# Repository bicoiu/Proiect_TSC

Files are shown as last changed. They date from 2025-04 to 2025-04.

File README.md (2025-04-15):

# TSC-Project

## BOM (Bill Of Materials)

| Component | Supplier Link | Datasheet |
|---|---|---|
| 112A-TAAR-R03 | [Model](https://store.comet.srl.ro/Catalogue/Product/43497/) | [Datasheet](https://www.snapeda.com/parts/112A-TAAR-R03/Attend/datasheet/) |
| 744043680 | [Model](https://ro.mouser.com/ProductDetail/Wurth-Elektronik/744043680?qs=PGXP4M47uW6VkZq%252BkzjrHA%3D%3D)| [Datasheet](https://www.we-online.com/components/products/datasheet/744043680.pdf) |
| BD5229G-TR | [Model](https://componentsearchengine.com/part-view/BD5229G-TR/ROHM%20Semiconductor) | [Datasheet](https://fscdn.rohm.com/en/products/databook/datasheet/ic/power/voltage_detector/bd52xxg-e.pdf) |
| Capacitor 0402 | [Model](https://ro.mouser.com/c/passive-components/capacitors/ceramic-capacitors/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) | [Datasheet](https://componentsearchengine.com/Datasheets/2/CC0402MRX5R5BB106.pdf) |
| CPH3225A | [Model](https://www.snapeda.com/parts/CPH3225A/Seiko+Instruments/view-part/?ref=snap) | [Datasheet](https://www.snapeda.com/parts/CPH3225A/Seiko%20Instruments/datasheet/) |
| Custom Button | [Model](https://industry.panasonic.com/global/en/products/control/switch/light-touch/number/evqpuj02k) | [Datasheet](https://industry.panasonic.com/global/en/downloads?tab=catalog&small_g_cd=203&part_no=EVQPUJ02K) |
| DS3231SN | [Model](https://www.snapeda.com/parts/DS3231SN%23/Analog+Devices/view-part/?ref=eda) | [Datasheet](https://www.snapeda.com/parts/DS3231SN%23/Analog%20Devices/datasheet/) |
| ESP32 WROVER 0805 Capacitor | [Model](https://componentsearchengine.com/part-view/ESP32-WROVER-IB/Espressif%20Systems) | [Datasheet](https://4donline.ihs.com/images/VipMasterIC/IC/ESPS/ESPS-S-A0016256762/ESPS-S-A0016256762-1.pdf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) |
| ESP32 WROVER BME680 Sensor | [Model](https://www.snapeda.com/parts/BME680/Bosch/view-part/?welcome=home) | [Datasheet](https://www.bosch-sensortec.com/media/boschsensortec/downloads/datasheets/bst-bme680-ds001.pdf) |
| ESP32 WROVER MCP73831 Power Management | [Model](https://www.snapeda.com/parts/BME680/Bosch/view-part/?welcome=home) | [Datasheet](https://www.snapeda.com/parts/MCP73831T-2ACI/OT/Microchip/datasheet/) |
| ESP32C6 Varistor 1812 | [Model](https://componentsearchengine.com/part-view/ESP32-C6-MINI-1-H4/Espressif%20Systems) | [Datasheet](https://4donline.ihs.com/images/VipMasterIC/IC/ESPS/ESPS-S-A0018537656/ESPS-S-A0018537656-1.pdf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) |
| ESP32C6 WROOM-1-N8 | [Model](https://www.snapeda.com/parts/ESP32-C6-WROOM-1-N8/Espressif+Systems/view-part/?ref=eda) | [Datasheet](https://www.snapeda.com/parts/ESP32-C6-WROOM-1-N8/Espressif%20Systems/datasheet/) |
| FH34SRJ-24S-0.5SH | [Model](https://ro.mouser.com/ProductDetail/Hirose-Connector/FH34SRJ-24S-0.5SH99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) | [Datasheet](https://www.snapeda.com/parts/FH34SRJ-24S-0.5SH(99)/Hirose%20Connector/datasheet/) |
| LED Chip 0603 | [Model](https://www.snapeda.com/parts/KP-1608SURCK/Kingbright/view-part/?ref=search&t=LED%200603) | [Datasheet](https://www.snapeda.com/parts/KP-1608SURCK/Kingbright/datasheet/) |
| MAX17048G+T10 | [Model](https://www.snapeda.com/parts/MAX17048G+T10/Analog+Devices/view-part/?ref=eda) | [Datasheet](https://www.snapeda.com/parts/MAX17048G+T10/Analog%20Devices/datasheet/) |
| MBR0530 Schottky Diode| [Model](https://www.snapeda.com/parts/MBR0530/Onsemi/view-part/?ref=snap) | [Datasheet](https://www.snapeda.com/parts/MBR0530/ON%20Semiconductor/datasheet/) |
| PGB1010603MR | [Model](https://www.snapeda.com/parts/PGB1010603MR/Littelfuse/view-part/?ref=eda) | [Datasheet](https://www.snapeda.com/parts/PGB1010603MR/Littelfuse%20Inc./datasheet/) |
| QWIIC Connector | [Model](https://www.snapeda.com/parts/PRT-14417/SparkFun/view-part/) | [Datasheet](https://www.snapeda.com/parts/PRT-14417/SparkFun%20Electronics/datasheet/) |
| RCL CPOL 3528 | [Model](https://www.snapeda.com/parts/CPH3225A/Seiko+Instruments/view-part/?ref=eda) | [Datasheet](https://s3.amazonaws.com/snapeda/datasheet/TAJB475K025RNJ_AVX.pdf) |
| Resistor 0402 | [Model](https://grabcad.com/library/resistor-0402-1) | [Datasheet](https://www.yageo.com/upload/media/product/products/datasheet/rchip/PYu-RC_Group_51_RoHS_L_12.pdf) |
| SI1308EDL-T1-GE3 MOSFET | [Model](https://www.snapeda.com/parts/SI1308EDL-T1-GE3/Vishay+Siliconix/view-part/?welcome=home&ref=eda) | [Datasheet](https://www.snapeda.com/parts/SI1308EDL-T1-GE3/Vishay%20Siliconix/datasheet/) |
| SJ | [Model](https://grabcad.com/library/solder-jumpers-1) | [Datasheet]() |
| USB4110-GF-A | [Model](https://componentsearchengine.com/part-view/USB4110-GF-A/GCT%20(GLOBAL%20CONNECTOR%20TECHNOLOGY))| [Datasheet](https://gct.co/files/drawings/usb4110.pdf) |
| USBLC6-2SC6Y | [Model](https://www.snapeda.com/parts/USBLC6-2SC6Y/STMicroelectronics/view-part/?welcome=home&ref=eda)  | [Datasheet](https://www.snapeda.com/parts/USBLC6-2SC6Y/STMicroelectronics/datasheet/) |
| W25Q512JVEIQ | [Model](https://www.snapeda.com/parts/W25Q512JVEIQ/Winbond+Electronics/view-part/?ref=eda) | [Datasheet](https://www.winbond.com/resource-files/W25Q512JV%20SPI%20RevB%2006252019%20KMS.pdf) |
| XC6220A331MR-G | [Model](https://componentsearchengine.com/part-view/XC6220A331MR-G/Torex) | [Datasheet](https://product.torexsemi.com/system/files/series/xc6220.pdf) |

## Hardware Description

1. **Microcontroller - ESP32-C6-WROOM-1-N8**  
   - Architecture: RISC-V 32-bit  
   - Clock Speed: 160 MHz  
   - Wireless Connectivity: 2.4 GHz Wi-Fi 6, Bluetooth 5.0  

2. **Power Management & Battery**  
   - Battery Type: Li-Po (Lithium Polymer), 3.7V, 1800mAh  
   - Charging Circuit: MCP73831T  
   - Input Voltage: 5V via USB-C  
   - Protection Features: Overcharge and deep discharge protection  
   - Voltage Regulator: LDO regulator for stable 3.3V supply  

3. **Display - E-Paper (E-Ink)**  
   - Size: 7.5 inches  
   - Resolution: 800x480 pixels  
   - Interface: SPI  

4. **SD Card Module**  
   - Type: MicroSD (FAT32 supported)  
   - Interface: SPI  

5. **External NOR Flash**  
   - Capacity: 64MB  
   - Interface: SPI  

6. **Environmental Sensor - BME688**  
   - Senses temperature, humidity, pressure, and gas  
   - Interface: I2C  

7. **Real-Time Clock (RTC) - DS3231SN**  
   - Maintains accurate time/date  
   - Interface: I2C  

8. **USB-C Connector & ESD Protection**  
   - Power input and data transfer  
   - ESD protection and Schottky diode for reverse polarity  

9. **Buttons & User Input**  
   - Tactile push buttons  

10. **Communication Interfaces**  
   - GPIO, SPI, I2C, UART, Wi-Fi, Bluetooth  

## Power Consumption Estimation

| Component | Current Draw (mA) | Voltage (V) | Power (mW) |
|---|---|---|---|
| ESP32-C6 (Wi-Fi active)  | 200 | 3.3 | 660 |
| E-Paper Display (Updating) | 40 | 3.3 | 132 |
| BME688 Sensor (Measuring)  | 3.1 | 3.3 | 10.23 |
| RTC Module (Active) | 0.15 | 3.3 | 0.495 |
| SD Card (Active) | 50 | 3.3 | 165 |
| External NOR Flash | 25 | 3.3 | 82.5 |
| **Total** | ~318.5mA | 3.3 | ~1050.72 |

## ESP32-C6 Pin Mapping

| Component | ESP32-C6 Pins | Interface | Purpose |
|---|---|---|---|
| **E-Paper Display** | IO7 (MOSI), IO6 (SCK), IO10 (CS), IO5 (DC), IO23 (RST), IO3 (BUSY) | SPI  | Transfers image data and controls e-paper state |
| **MicroSD Card** | IO7 (MOSI), IO6 (SCK), IO4 (SS_SD), IO2 (MISO) | SPI  | Storage and retrieval of e-books |
| **Environmental Sensor (BME688)** | IO21 (SDA), IO22 (SCL) | I2C | Reads temperature, humidity, pressure, and gas levels |
| **RTC Module (DS3231)** | IO21 (SDA), IO22 (SCL), IO18 (RST), IO1 (32KHz), IO0 (INT_RTC) | I2C | Maintains time tracking when system is off |
| **External NOR Flash** | IO11 (CS), IO6 (SCK), IO2 (MISO), IO7 (MOSI) | SPI  | Additional storage for data |
| **Battery Monitoring** | IO21 (SDA), IO22 (SCL) | I2C | Reads battery voltage and charge status |
| **USB-C Connection** | GPIOs via voltage regulation | USB | Powers and programs the ESP32-C6 |
| **Control Buttons** | IO9 (BOOT), IO15 (CHANGE), EN (RESET)  | GPIO | User input for device interactions |

## Additional Design Notes

### Footprint Adjustments
- **Diode (SMD-Hole)**: The original footprint had pad holes too small for reliable soldering. Pads were updated to 35mil x 190mil.  
- **U4 – MAX17048G+T10**: VBAT power trace width was 0.3mm, while pin widths were only 0.27mm. Adjusted pin size to match trace width.

### Routing & Ground Plane
- Power traces are on the top layer; ~150 vias used for bottom-layer signals.  
- Ground plane on both top and bottom layers for low-impedance grounding and reduced EMI.

### Component Placement
- External ports align with the OpenBook enclosure for accessibility.  
- Test pads near board edges for easy debugging.  
- 100nF decoupling capacitors placed close to IC power pins for noise reduction.

### Schematic & 3D Model Issues
- A net named GND1 appeared but was not functional; removed after review.  
- 3D model updates caused pin order reversals for certain 2-pin components, fixed by rotating 180 degrees.

### Enclosure & 3D Integration
- An alternative enclosure was tested with a custom color.  
- 3D components were imported via two methods depending on their usage frequency.

### Difficulties Encountered
- Am intampinat dificultati la realizarea schematicului pana am inceput sa ma documentez.  
- In etapa de proiectare PCB, cea mai mare provocare a fost sa asez toate componentele in dimensiunile cerute.  
- Rutarea finala a fost de asemenea dificila, necesitand mai multe iteratii pentru a organiza corespunzator toate traseele.

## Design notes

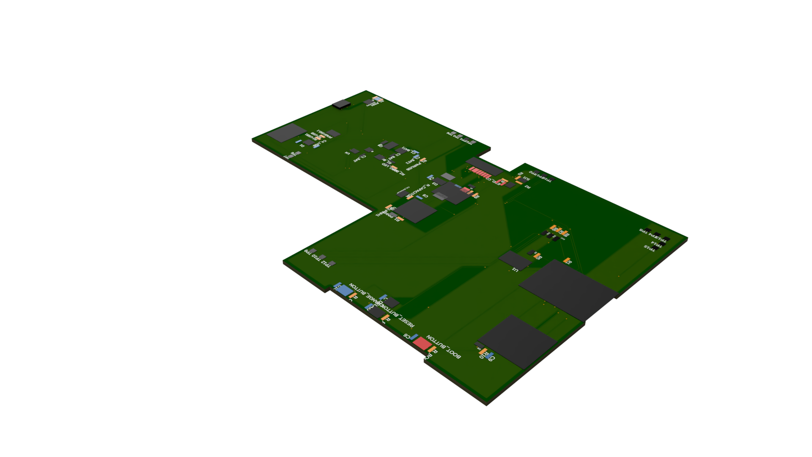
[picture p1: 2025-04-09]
Hardware/board.png

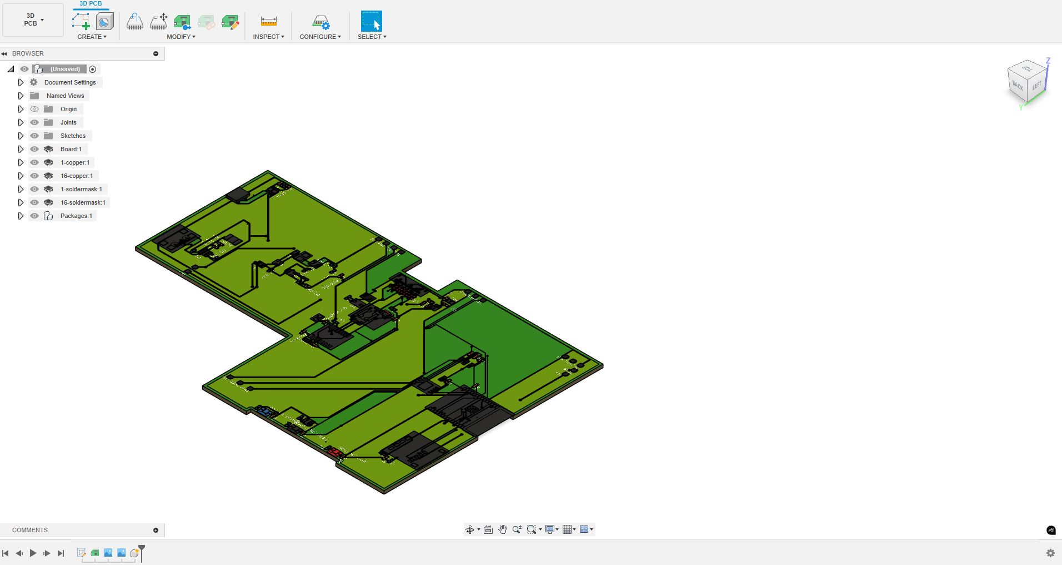
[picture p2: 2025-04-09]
Images/bord.png

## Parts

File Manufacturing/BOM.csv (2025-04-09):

Qty | Value | Device | Footprint Name | Parts | Detailed Description | ARROW_PART_NUMBER | ARROW_PRICE-STOCK | AVAILABILITY | CENTROID_NOT_SPECIFIED | CHECK_PRICES | COPYRIGHT | DATASHEET | DESCRIPTION | DIGIKEY_DESCRIPTION | DIGIKEY_PART_NUMBER | HEIGHT | LEAD_FREE | MANUFACTURER_NAME | MANUFACTURER_PART_NUMBER | MF | MFR_NAME | MOUSER_PART_NUMBER | MOUSER_PRICE-STOCK | MOUSER_TESTING_PART_NUMBER | MOUSER_TESTING_PRICE-STOCK | MP | MPN | PACKAGE | POPULARITY | PREFIX | PRICE | PROD_ID | PURCHASE-URL | ROHS | SNAPEDA_LINK | SPICEMODEL | SPICEPREFIX | TEMPERATURE_RANGE_HIGH | TEMPERATURE_RANGE_LOW | TP_SIGNAL_NAME | VALUE
1 |  | ADAFRUIT_LEDCHIP-LED0603 | ADAFRUIT_CHIP-LED0603 | CHG_LED | LED
1 |  | SJ | SJ | SJ1 | SMD solder JUMPER |  |  |  |  |  |  |  |  |  |  |  |  |  |  |  |  |  |  |  |  |  |  |  | 3
1 | 0.1uF/50V | ESP32_WROVER_EAGLE-LTSPICE_CC0402 | ESP32_WROVER_EAGLE-LTSPICE_C0402 | C18 | CAPACITOR, European symbol |  |  |  |  |  |  |  |  |  |  |  |  |  |  |  |  |  |  |  |  |  |  |  |  |  |  |  |  |  |  | NONE | C
1 | 0.47 | ESP32_WROVER_EAGLE-LTSPICE_RR0402 | ESP32_WROVER_EAGLE-LTSPICE_R0402 | R6 | RESISTOR, European symbol |  |  |  |  |  |  |  |  |  |  |  |  |  |  |  |  |  |  |  |  |  |  |  |  |  |  |  |  |  |  | NONE | R
1 | 100K | ESP32_WROVER_EAGLE-LTSPICE_RR0402 | ESP32_WROVER_EAGLE-LTSPICE_R0402 | R1_PWRUSB | RESISTOR, European symbol |  |  |  |  |  |  |  |  |  |  |  |  |  |  |  |  |  |  |  |  |  |  |  |  |  |  |  |  |  |  | NONE | R
9 | 100nF | ESP32_WROVER_EAGLE-LTSPICE_CC0402 | ESP32_WROVER_EAGLE-LTSPICE_C0402 | C1, C6, C8, C21, C22, C23, C25, C26, C_DELAY | CAPACITOR, European symbol |  |  |  |  |  |  |  |  |  |  |  |  |  |  |  |  |  |  |  |  |  |  |  |  |  |  |  |  |  |  | NONE | C
1 | 100uF | RCL_CPOL-EUCT3528 | RCL_CT3528 | TANT | POLARIZED CAPACITOR, European symbol |  |  |  |  |  |  |  |  |  |  |  |  |  |  |  |  |  |  |  |  |  |  |  | 0 |  |  |  |  |  |  |  | C
15 | 10K | ESP32_WROVER_EAGLE-LTSPICE_RR0402 | ESP32_WROVER_EAGLE-LTSPICE_R0402 | R1_PINH, R1_PINH1, R2-PINH, R2-PINH1, R7, R17, R18, R19, R20, R21, R22, R_BOOT, R_CHANGE, R_CL1, R_RESET | RESISTOR, European symbol |  |  |  |  |  |  |  |  |  |  |  |  |  |  |  |  |  |  |  |  |  |  |  |  |  |  |  |  |  |  | NONE | R
1 | 10uF | ESP32_WROVER_EAGLE-LTSPICE_CC0402 | ESP32_WROVER_EAGLE-LTSPICE_C0402 | C7 | CAPACITOR, European symbol |  |  |  |  |  |  |  |  |  |  |  |  |  |  |  |  |  |  |  |  |  |  |  |  |  |  |  |  |  |  | NONE | C
1 | 112A-TAAR-R03_ATTEND | 112A-TAAR-R03_ATTEND | 112ATAARR03ATTEND | J2 | Micro SD Card Socket, Push-Push Type, Top Mount, SMT, H=1.83mm, 10u |  |  |  |  |  |  |  | Micro SD Card Socket, Push-Push Type, Top Mount, SMT, H=1.83mm, 10u |  |  | 1.9mm |  | ATTEND | 112A-TAAR-R03 ATTEND
1 | 15 | ESP32_WROVER_EAGLE-LTSPICE_RR0402 | ESP32_WROVER_EAGLE-LTSPICE_R0402 | R_CAPACITOR | RESISTOR, European symbol |  |  |  |  |  |  |  |  |  |  |  |  |  |  |  |  |  |  |  |  |  |  |  |  |  |  |  |  |  |  | NONE | R
1 | 1uF | ESP32_WROVER_EAGLE-LTSPICE_CC0402 | ESP32_WROVER_EAGLE-LTSPICE_C0402 | C24 | CAPACITOR, European symbol |  |  |  |  |  |  |  |  |  |  |  |  |  |  |  |  |  |  |  |  |  |  |  |  |  |  |  |  |  |  | NONE | C
9 | 1uF/50V | ESP32_WROVER_EAGLE-LTSPICE_CC0402 | ESP32_WROVER_EAGLE-LTSPICE_C0402 | C11, C12, C13, C14, C15, C16, C17, C19, C20 | CAPACITOR, European symbol |  |  |  |  |  |  |  |  |  |  |  |  |  |  |  |  |  |  |  |  |  |  |  |  |  |  |  |  |  |  | NONE | C
1 | 2.2 | ESP32_WROVER_EAGLE-LTSPICE_RR0402 | ESP32_WROVER_EAGLE-LTSPICE_R0402 | R5 | RESISTOR, European symbol |  |  |  |  |  |  |  |  |  |  |  |  |  |  |  |  |  |  |  |  |  |  |  |  |  |  |  |  |  |  | NONE | R
1 | 200 | ESP32_WROVER_EAGLE-LTSPICE_RR0402 | ESP32_WROVER_EAGLE-LTSPICE_R0402 | R1_BAT | RESISTOR, European symbol |  |  |  |  |  |  |  |  |  |  |  |  |  |  |  |  |  |  |  |  |  |  |  |  |  |  |  |  |  |  | NONE | R
2 | 20V/4.2A/52mO/1.4W | ESP32_WROVER_SPARKFUN-DISCRETESEMI_MOSFET_PCH-DMG2305UX-7 | ESP32_WROVER_SPARKFUN-DISCRETESEMI_SOT23-3 | Q1, Q3 | P-channel MOSFETs |  |  |  |  |  |  |  |  |  |  |  |  |  |  |  |  |  |  |  |  |  |  |  |  |  |  | TRAN-14388 |  |  |  |  |  |  |  |  | 20V/4.2A/52mO/1.4W
2 | 2K | ESP32_WROVER_EAGLE-LTSPICE_RR0402 | ESP32_WROVER_EAGLE-LTSPICE_R0402 | R2_BAT, R10 | RESISTOR, European symbol |  |  |  |  |  |  |  |  |  |  |  |  |  |  |  |  |  |  |  |  |  |  |  |  |  |  |  |  |  |  | NONE | R
5 | 4.7uF | ESP32_WROVER_EAGLE-LTSPICE_CC0402 | ESP32_WROVER_EAGLE-LTSPICE_C0402 | C1_BAT, C1_BAT1, C1_BAT2, C2, C2_BAT | CAPACITOR, European symbol |  |  |  |  |  |  |  |  |  |  |  |  |  |  |  |  |  |  |  |  |  |  |  |  |  |  |  |  |  |  | NONE | C
2 | 5k1 | ESP32_WROVER_EAGLE-LTSPICE_RR0402 | ESP32_WROVER_EAGLE-LTSPICE_R0402 | R2-USB1, R2-USB2 | RESISTOR, European symbol |  |  |  |  |  |  |  |  |  |  |  |  |  |  |  |  |  |  |  |  |  |  |  |  |  |  |  |  |  |  | NONE | R
1 | 68uH | 744043680IND_4828-WE-TPC_WRE | IND_4828-WE-TPC_WRE | L2 |  |  |  |  |  |  | Copyright (C) 2024 Ultra Librarian. All rights reserved. |  |  |  |  |  |  |  | 744043680 |  | Wurth Electronics
1 | BD5229G-TR | BD5229G-TR | SOT95P280X125-5N | IC2 | Voltage Detector with Adjustable Delay Time: CMOS processes are utilized to develop high precision, low current consumption CMOS reset ICs that allow arbitrary setting of the delay time. The extensive lineup includes both Nch Open Drain and CMOS output types in a wide range of detection voltages (from 2.3V to 6.0V, in 0.1V steps), enabling selection of the ideal solution based on customer requirements. In addition, the entire series is of course both lead-free and RoHS-compliant. |  |  |  |  |  |  |  | Voltage Detector with Adjustable Delay Time: CMOS processes are utilized to develop high precision, low current consumption CMOS reset ICs that allow arbitrary setting of the delay time. The extensive lineup includes both Nch Open Drain and CMOS output types in a wide range of detection voltages (from 2.3V to 6.0V, in 0.1V steps), enabling selection of the ideal solution based on customer requirements. In addition, the entire series is of course both lead-free and RoHS-compliant. |  |  | 1.25mm |  | ROHM Semiconductor | BD5229G-TR |  |  | 755-BD5229G-TR | https://www.mouser.co.uk/ProductDetail/ROHM-Semiconductor/BD5229G-TR?qs=4kLU8WoGk0vvnhrrYwdszw%3D%3D
1 | BME688 | ESP32_WROVER_BME680_BME680 | ESP32_WROVER_BME680_PSON80P300X300X100-8N | U3 | Integrated Environmental Unit |  |  | Unavailable |  |  |  |  | Integrated Environmental Unit |  |  |  |  |  |  | Bosch Sensortec |  |  |  |  |  | BME680 |  | LGA-8 Bosch Tools |  |  | None
1 | BOOT_BUTTON | BUTTON_CUSYOMV1 | MYBUTTON | U$2
1 | C10_SUPERCAP | ESP32_WROVER_EAGLE-LTSPICE_CC0402 | ESP32_WROVER_EAGLE-LTSPICE_C0402 | CPH3225A | CAPACITOR, European symbol |  |  |  |  |  |  |  |  |  |  |  |  |  |  |  |  |  |  |  |  |  |  |  |  |  |  |  |  |  |  | NONE | C
1 | CHANGE_BUTTON | BUTTON_CUSYOMV1 | MYBUTTON | PUSH
1 | DS3231SN# | DS3231SN# | SOIC127P1032X265-16N | U5 | Real Time Clock Serial 16-Pin SOIC W T/R Check availability |  |  | In Stock |  | https://www.snapeda.com/parts/DS3231SN%23/Analog+Devices/view-part/?ref=eda |  |  | Extremely Accurate I²C-Integrated RTC/TCXO/Crystal |  |  |  |  |  |  | Analog Devices |  |  |  |  |  | DS3231SN# |  | SOIC-16 Maxim |  |  | None |  | https://www.snapeda.com/api/url_track_click_mouser/?unipart_id=99048&manufacturer=Analog Devices&part_name=DS3231SN#&search_term=None |  | https://www.snapeda.com/parts/DS3231SN%23/Analog+Devices/view-part/?ref=snap
1 | ESP32-C6-WROOM-1-N8 | ESP32-C6-WROOM-1-N8 | XCVR_ESP32-C6-WROOM-1-N8 | U2 | Check availability |  |  | In Stock |  | https://www.snapeda.com/parts/ESP32-C6-WROOM-1-N8/Espressif+Systems/view-part/?ref=eda |  |  | Multiprotocol Modules ESP32-C6 module, Wi-Fi 6 in 2.4 GHz band, Bluetooth 5, Zigbee 3.0 and Thread. ESP34-WROOM Compatible - ENGINEERING SAMPLE |  |  |  |  |  |  | Espressif Systems |  |  |  |  |  | ESP32-C6-WROOM-1-N8 |  | None |  |  | None |  |  |  | https://www.snapeda.com/parts/ESP32-C6-WROOM-1-N8/Espressif+Systems/view-part/?ref=snap
1 | ESP32C6_VARISTORCN1812 | ESP32C6_VARISTORCN1812 | ESP32C6_VARISTOR_CT/CN1812 | PFMF.050.1 | VARISTOR |  |  |  |  |  |  |  |  |  |  |  |  |  |  |  |  |  |  |  |  |  |  |  | 0
2 | ESP32_WROVER_AVX---SD0805S020S1R0_AVX_SD0805S020S1R0_0_0AVX_SD0805S020S1R0_0_0 | ESP32_WROVER_AVX---SD0805S020S1R0_AVX_SD0805S020S1R0_0_0AVX_SD0805S020S1R0_0_0 | ESP32_WROVER_AVX---SD0805S020S1R0_AVX_SD0805S020S1R0_0 | D2, D6 | Schottky Barrier Rectifier Diode |  |  |  | No |  |  | http://datasheets.avx.com/schottky.pdf |  | DIODE SCHOTTKY 20V 1A 0805 | 478-7800-1-ND |  | yes |  |  | AVX |  | 581-SD0805S020S1R0 |  |  |  |  |  | 0805 (2012 metric) |  | D |  |  |  | yes |  |  |  | +125°C | -55°C
1 | ESP32_WROVER_SPARKFUN-IC-POWER_MCP73831 | ESP32_WROVER_SPARKFUN-IC-POWER_MCP73831 | ESP32_WROVER_SPARKFUN-IC-POWER_SOT23-5 | U1 | MCP73831T Li-Ion, Li-Pol Controller |  |  |  |  |  |  |  |  |  |  |  |  |  |  |  |  |  |  |  |  |  |  |  |  |  |  | IC-09995
1 | FH34SRJ-24S-0.5SH_99_ | FH34SRJ-24S-0.5SH_99_ | FH34SRJ24S05SH99 | J3 | 24 Position FFC, FPC Connector Contacts, Top and Bottom 0.020 (0.50mm) Surface Mount, Right Angle" |  |  |  |  |  |  |  | 24 Position FFC, FPC Connector Contacts, Top and Bottom 0.020 (0.50mm) Surface Mount, Right Angle" |  |  | 1.1mm |  | Hirose | FH34SRJ-24S-0.5SH(99) |  |  | 798-FH34SRJ24S05SH99 | https://www.mouser.co.uk/ProductDetail/Hirose-Connector/FH34SRJ-24S-0.5SH99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
1 | MAX17048G+T10 | MAX17048G+T10 | SON50P200X200X80-9N | U4 | Check availability |  |  | In Stock |  | https://www.snapeda.com/parts/MAX17048G+T10/Analog+Devices/view-part/?ref=eda |  |  | 3µA 1-Cell/2-Cell Fuel Gauge with ModelGauge |  |  |  |  |  |  | Analog Devices |  |  |  |  |  | MAX17048G+T10 |  | TDFN-8 Maxim |  |  | None |  | https://www.snapeda.com/api/url_track_click_mouser/?unipart_id=329239&manufacturer=Analog Devices&part_name=MAX17048G+T10&search_term=None |  | https://www.snapeda.com/parts/MAX17048G+T10/Analog+Devices/view-part/?ref=snap
3 | MBR0530 | MBR0530 | SOD3716X135N | D3, D4, D5 | ON SEMICONDUCTOR - MBR0530 - DIODE, SCHOTTKY, 0.5A, 30V, SOD-123 |  |  | In Stock |  | https://www.snapeda.com/parts/MBR0530/Onsemi/view-part/?ref=eda |  |  | Diode Schottky 30 V 500mA Surface Mount SOD-123 |  |  |  |  |  |  | ON Semiconductor |  |  |  |  |  | MBR0530 |  | SOD-123-2 ON Semiconductor |  |  | None |  | https://www.snapeda.com/api/url_track_click_mouser/?unipart_id=179458&manufacturer=ON Semiconductor&part_name=MBR0530&search_term=None |  | https://www.snapeda.com/parts/MBR0530/Onsemi/view-part/?ref=snap
6 | PGB1010603MR | PGB1010603MR | DIOC1608X36N | D7, D8, D9, D10, D11, D12 | Check availability |  |  | In Stock |  | https://www.snapeda.com/parts/PGB1010603MR/Littelfuse/view-part/?ref=eda |  |  | 150V (Typ) Clamp - Ipp Tvs Diode Surface Mount 0603 (1608 Metric) |  |  |  |  |  |  | Littelfuse Inc. |  |  |  |  |  | PGB1010603MR |  | 0603 Littelfuse Inc. |  |  | None |  | https://www.snapeda.com/api/url_track_click_mouser/?unipart_id=5659453&manufacturer=Littelfuse Inc.&part_name=PGB1010603MR&search_term=None |  | https://www.snapeda.com/parts/PGB1010603MR/Littelfuse/view-part/?ref=snap
1 | QWIIC_RIGHT_ANGLE | QWIIC_CONNECTORJS-1MM | JST04_1MM_RA | J4 | SparkFun I2C Standard Qwiic Connector |  |  |  |  |  |  |  |  |  |  |  |  |  |  |  |  |  |  |  |  |  |  |  |  |  |  | CONN-13694 |  |  |  |  |  |  |  |  | QWIIC_RIGHT_ANGLE
1 | RESET_BUTTON | BUTTON_CUSYOMV1 | MYBUTTON | RESET_BUTTON
1 | SAMACSYS_PARTS_USB4110-GF-A | SAMACSYS_PARTS_USB4110-GF-A | SAMACSYS_PARTS_USB4110GFA | J1 | CONN USB 2.0 TYPE-C R/A SMT |  |  |  |  |  |  |  | CONN USB 2.0 TYPE-C R/A SMT |  |  | 3.26mm |  | GCT (GLOBAL CONNECTOR TECHNOLOGY) | USB4110-GF-A |  |  | 640-USB4110-GF-A | https://www.mouser.co.uk/ProductDetail/GCT/USB4110-GF-A?qs=KUoIvG%2F9IlYiZvIXQjyJeA%3D%3D
1 | SI1308EDL-T1-GE3 | SI1308EDL-T1-GE3 | SOT65P210X110-3N | Q2 | MOSFET N-Ch 30V 1.5A TrenchFET SC70 Vishay Si1308EDL-T1-GE3 N-channel MOSFET Transistor, 1.5 A, 30 V, 3-Pin SC-70 |  |  | In Stock |  | https://www.snapeda.com/parts/SI1308EDL-T1-GE3/Vishay+Siliconix/view-part/?ref=eda |  |  | Si1308EDL-T1-GE3 N-channel MOSFET Transistor, 1.5 A, 30 V, 3-Pin SC-70 | Siliconix / Vishay SI1308EDL-T1-GE3 |  |  |  |  |  |  | Vishay Siliconix |  |  |  |  |  | SI1308EDL-T1-GE3 |  | SOT-323 Vishay Semiconductor |  |  | None |  | https://www.snapeda.com/api/url_track_click_mouser/?unipart_id=274603&manufacturer=Vishay Siliconix&part_name=SI1308EDL-T1-GE3&search_term=None |  | https://www.snapeda.com/parts/SI1308EDL-T1-GE3/Vishay+Siliconix/view-part/?ref=snap
17 | TPTP20R | TPTP20R | TP20R | TP1, TP2, TP3, TP4, TP5, TP6, TP7, TP8, TP9, TP10, TP11, TP12, TP13, TP14, TP15, TP16, TP17 | Test pad |  |  |  |  |  |  |  |  |  |  |  |  |  |  |  |  |  |  |  |  |  |  |  | 2
1 | USBLC6-2SC6Y | USBLC6-2SC6Y | SOT95P280X145-6N | D1 | Low Cap. ESD Protection Auto SOT-23-6 STMicroelectronics USBLC6-2SC6Y, Dual Uni-Directional TVS Diode Array, 6-Pin SOT-23 |  |  | In Stock |  | https://www.snapeda.com/parts/USBLC6-2SC6Y/STMicroelectronics/view-part/?ref=eda |  |  | 17V Clamp 5A (8/20µs) Ipp Tvs Diode Surface Mount SOT-23-6 |  |  |  |  |  |  | STMicroelectronics |  |  |  |  |  | USBLC6-2SC6Y |  | SOT-23-6 STMicroelectronics |  |  | None |  |  |  | https://www.snapeda.com/parts/USBLC6-2SC6Y/STMicroelectronics/view-part/?ref=snap
1 | W25Q512JVEIQ | W25Q512JVEIQ | SON127P600X800X80-9N | U6 | Check availability |  |  | In Stock |  | https://www.snapeda.com/parts/W25Q512JVEIQ/Winbond+Electronics/view-part/?ref=eda |  |  | FLASH - NOR Memory IC 512Mb (64M x 8) SPI - Quad I/O 133 MHz 8-WSON (8x6) |  |  |  |  |  |  | Winbond Electronics |  |  |  |  |  | W25Q512JVEIQ |  | Package |  |  | None |  |  |  | https://www.snapeda.com/parts/W25Q512JVEIQ/Winbond+Electronics/view-part/?ref=snap
1 | XC6220A331MR-G | XC6220A331MR-G | SOT95P280X120-5N | IC1 | LDO Voltage Regulators |  |  |  |  |  |  |  | LDO Voltage Regulators |  |  | 1.2mm |  | Torex | XC6220A331MR-G |  |  | 865-XC6220A331MR-G | https://www.mouser.co.uk/ProductDetail/Torex-Semiconductor/XC6220A331MR-G?qs=AsjdqWjXhJ8ZSWznL1J0gg%3D%3D

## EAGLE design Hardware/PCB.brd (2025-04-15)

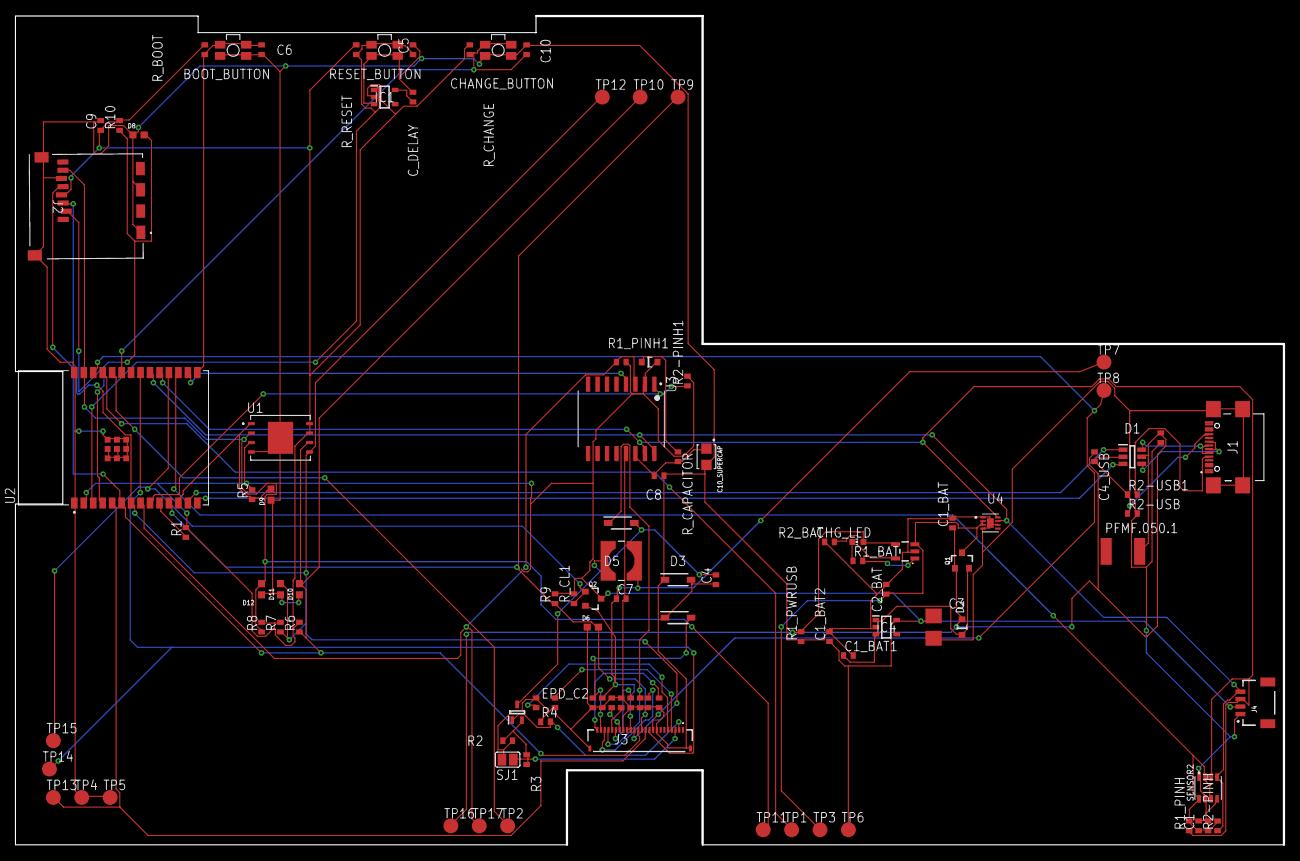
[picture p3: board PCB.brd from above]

Board: 2 copper layers, 170.2 x 111.2 mm, 103 parts (0 on the bottom side), 54 nets.

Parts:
BOOT_BUTTON: BUTTON_CUSYOMV1; MYBUTTON
C1, C2, C6, C8, C10: 100nF; EAGLE-LTSPICE_C0402
C1_BAT, C5_USB: 4.7uF; ESP32_WROVER_EAGLE-LTSPICE_C0402
C1_BAT1, C1_BAT2, C2_BAT: 4.7uF; EAGLE-LTSPICE_C0402
C3: 100uF; RCL_CT3528
C4: 4.7uF/25V; EAGLE-LTSPICE_C0402
C4_USB, C9: 100nF; ESP32_WROVER_EAGLE-LTSPICE_C0402
C5: 1uF; EAGLE-LTSPICE_C0402
C7: 10uF; EAGLE-LTSPICE_C0402
C10_SUPERCAP: CPH3225A; CAPCP3225X100N
CHANGE_BUTTON: BUTTON_CUSYOMV1; MYBUTTON
CHG_LED: ADAFRUIT_CHIP-LED0603
C_DELAY: 100nF; EAGLE-LTSPICE_C0402
D1: USBLC6-2SC6Y; SOT95P280X145-6N
D2, D7: ESP32_WROVER_AVX---SD0805S020S1R0_AVX_SD0805S020S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; ESP32_WROVER_AVX---SD0805S020S1R0_AVX_SD0805S020S1R0_0
D3, D4, D5: MBR0530; SOD3716X135N
D6, D8, D9, D10, D11, D12: PGB1010603MR; DIOC1608X36N
EPD_C1, EPD_C2, EPD_C5, EPD_C6, EPD_C7, EPD_C8, EPD_C9, EPD_C11, EPD_C12: 1uF/50V; EAGLE-LTSPICE_C0402
EPD_C10: EAGLE-LTSPICE_C0402
IC1: BD5229G-TR; SOT95P280X125-5N
IC4: XC6220A331MR-G; SOT95P280X120-5N
J1: SAMACSYS_PARTS_USB4110-GF-A; SAMACSYS_PARTS_USB4110GFA
J2: 112A-TAAR-R03_ATTEND; 112ATAARR03ATTEND
J3: FH34SRJ-24S-0.5SH_99_; FH34SRJ24S05SH99
J4: QWIIC_RIGHT_ANGLE; JST04_1MM_RA
L1: 744043680IND_4828-WE-TPC_WRE; IND_4828-WE-TPC_WRE
MCP73831: ESP32_WROVER_SPARKFUN-IC-POWER_MCP73831; ESP32_WROVER_SPARKFUN-IC-POWER_SOT23-5
PFMF.050.1: ESP32C6_VARISTORCN1812; ESP32C6_VARISTOR_CT/CN1812
Q1, Q2: 20V/4.2A/52mΩ/1.4W; ESP32_WROVER_SPARKFUN-DISCRETESEMI_SOT23-3
Q3: SI1308EDL-T1-GE3; SOT65P210X110-3N
R1, R4: 10K; ESP32_WROVER_EAGLE-LTSPICE_R0402
R1_BAT: 200; ESP32_WROVER_EAGLE-LTSPICE_R0402
R1_PINH, R1_PINH1, R2-PINH, R2-PINH1, R5, R6, R7, R8, R9, R10: 10k; ESP32_WROVER_EAGLE-LTSPICE_R0402
R1_PWRUSB: 100k; ESP32_WROVER_EAGLE-LTSPICE_R0402
R2: 2.2; ESP32_WROVER_EAGLE-LTSPICE_R0402
R2-USB, R2-USB1: 5k1; ESP32_WROVER_EAGLE-LTSPICE_R0402
R2_BAT: 2k; ESP32_WROVER_EAGLE-LTSPICE_R0402
R3: 0.47; ESP32_WROVER_EAGLE-LTSPICE_R0402
RESET_BUTTON: BUTTON_CUSYOMV1; MYBUTTON
R_BOOT: 10k; ESP32_WROVER_EAGLE-LTSPICE_R0402
R_CAPACITOR: 15; ESP32_WROVER_EAGLE-LTSPICE_R0402
R_CHANGE: 10k; ESP32_WROVER_EAGLE-LTSPICE_R0402
R_CL1: 10k; ESP32_WROVER_EAGLE-LTSPICE_R0402
R_RESET: 10k; ESP32_WROVER_EAGLE-LTSPICE_R0402
SENSOR2: ESP32_WROVER_BME680_BME680; ESP32_WROVER_BME680_PSON80P300X300X100-8N
SJ1: SJ
TP1, TP2, TP3, TP4, TP5, TP6, TP7, TP8, TP9, TP10, TP11, TP12, TP13, TP14, TP15, TP16, TP17: TPTP20R; TP20R
U1: W25Q512JVEIQ; SON127P600X800X80-9N
U2: ESP32-C6-WROOM-1-N8; XCVR_ESP32-C6-WROOM-1-N8
U3: DS3231SN#; SOIC127P1032X265-16N
U4: MAX17048G+T10; SON50P200X200X80-9N

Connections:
3V3: C1_BAT2.1, C3.+, C9.1, D7.2, IC1.2, IC4.5, J2.P4, J4.2, Q2.3, R1.2, R1_PINH1.2, R2-PINH1.2, R5.2, R6.2, R7.2, R8.2, R9.2, R10.2, R_BOOT.2, R_CHANGE.2, R_CL1.2, R_RESET.2, TP6.TP, U1.3, U1.7, U1.8, U2.2, U3.2
32KHZ: R2-PINH1.1, U2.9, U3.1
DN: D1.6, J1.A7, J1.B7
DP: D1.4, J1.A6, J1.B6
EPD_3V3: C7.1, EPD_C5.2, J3.15, J3.16, L1.2, Q2.2, TP7.TP
EPD_3V3_C: Q2.1, R_CL1.1, TP15.TP, U2.18
EPD_BUSY: J3.9, TP8.TP, U2.26
EPD_CS: D6.2, J3.12, R9.1, TP9.TP, U2.11
EPD_DC: J3.11, TP13.TP, U2.5
EPD_RST: J3.10, TP14.TP, U2.21
FLASH_CS: D9.2, R5.1, U1.1, U2.12
GDR: J3.2, Q3.1, R4.2
GND: BOOT_BUTTON.1, BOOT_BUTTON.2, C1.2, C1_BAT.2, C1_BAT1.2, C1_BAT2.2, C2.2, C2_BAT.2, C3.-, C4_USB.2, C5.2, C5_USB.2, C6.2, C7.2, C8.2, C9.2, C10.2, C10_SUPERCAP.2, CHANGE_BUTTON.1, CHANGE_BUTTON.2, C_DELAY.2, D1.2, D3.1, D6.1, D8.1, D9.1, D10.1, D11.1, D12.1, EPD_C1.1, EPD_C2.1, EPD_C5.1, EPD_C6.1, EPD_C7.1, EPD_C8.1, EPD_C9.1, EPD_C10.1, EPD_C11.1, EPD_C12.1, IC1.3, IC4.2, J1.A1, J1.A12, J1.B1, J1.B12, J1.MP1, J1.MP2, J1.MP3, J1.MP4, J2.G1, J2.G2, J2.G3, J2.G4, J2.P6, J3.8, J3.17, J3.MP1, J3.MP2, J4.1, MCP73831.2, R1_PWRUSB.1, R2.1, R2-USB.2, R2-USB1.1, R2_BAT.1, R4.1, RESET_BUTTON.1, RESET_BUTTON.2, SENSOR2.1, SENSOR2.5, SENSOR2.7, SJ1.1, TP4.TP, TP5.TP, U1.4, U1.9, U2.1, U2.28, U2.29_1, U2.29_2, U2.29_3, U2.29_4, U2.29_5, U2.29_6, U2.29_7, U2.29_8, U2.29_9, U3.13, U4.1, U4.4, U4.6, U4.9
GPIO8: R1.1, U2.10
I2C_PW: C1.1, C2.1, R1_PINH.2, R2-PINH.2, SENSOR2.2, SENSOR2.6, SENSOR2.8, U2.17
INT_RTC: R1_PINH1.1, TP17.TP, U2.8, U3.3
IO/BOOT: BOOT_BUTTON.3, BOOT_BUTTON.4, C6.1, R_BOOT.1, U2.15
IO/CHANGE: C10.1, CHANGE_BUTTON.3, CHANGE_BUTTON.4, R_CHANGE.1, U2.23
MISO: D12.2, J2.P7, R8.1, TP11.TP, U1.2, U2.27
MOSI: D11.2, J2.P3, J3.14, R7.1, TP12.TP, U1.5, U2.7
unnamed: C_DELAY.1, IC1.5
unnamed: J1.B5, R2-USB.1
unnamed: J1.A5, R2-USB1.2
unnamed: C1_BAT1.1, D2.1, IC4.1, IC4.3, Q1.2
unnamed: C4.1, D3.2, D4.1
unnamed: MCP73831.1, R1_BAT.2
unnamed: CHG_LED.C, R1_BAT.1
unnamed: MCP73831.5, R2_BAT.2
unnamed: EPD_C1.2, J3.4
unnamed: EPD_C2.2, J3.5
unnamed: EPD_C12.2, J3.24
unnamed: EPD_C10.2, J3.22
unnamed: EPD_C8.2, J3.20
unnamed: EPD_C7.2, J3.19
unnamed: EPD_C6.2, J3.18
unnamed: D7.1, R_CAPACITOR.1
PREVGH: D5.1, EPD_C9.2, J3.21
PREVGL: D4.2, EPD_C11.2, J3.23
RESE: J3.3, Q3.2, R2.2, R3.1, R3.2, SJ1.2
RESET: C5.1, IC1.1, RESET_BUTTON.3, RESET_BUTTON.4, R_RESET.1, U2.3
RTC_RST: U2.16, U3.4
RX: TP2.TP, U2.24
SCK: D10.2, J2.P5, J3.13, R6.1, TP10.TP, U1.6, U2.6
SCL: J4.4, R2-PINH.1, SENSOR2.4, U2.20, U3.16, U4.7
SDA: J4.3, R1_PINH.1, SENSOR2.3, U2.19, U3.15, U4.8
SRC: C4.2, D5.2, L1.1, Q3.3
SS_SD: D8.2, J2.P2, R10.1, U2.4
TX: TP1.TP, U2.25
USB_D+: D1.3, U2.14
USB_D-: D1.1, U2.13
VBAT: C2_BAT.1, MCP73831.3, Q1.3, TP3.TP, U4.2, U4.3
VBUS: C1_BAT.1, C4_USB.1, C5_USB.1, CHG_LED.A, D1.5, D2.2, MCP73831.4, PFMF.050.1.2, Q1.1, R1_PWRUSB.2, TP16.TP
VRTC: C8.1, C10_SUPERCAP.1, R_CAPACITOR.2, U3.14
VUSB: J1.A4, J1.A9, J1.B4, J1.B9, PFMF.050.1.1

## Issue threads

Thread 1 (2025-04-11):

EPaper Display header shorted to ground

Bedodev, 2025-04-11:
Pin 21 of the ePaper Display header is connected to ground instead of PREVGH.

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

Closed 2025-04-15.

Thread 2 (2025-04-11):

TX testpad not connected to TX net

Bedodev, 2025-04-11:
Although connected in the pcb, in the schematic the TX label is connected to the TX pin on the mcu, but on the TX testpad is visually in the correct spot and floating/disconnected electrically. An example has been added showing this compared to the connected rx label.

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

Closed 2025-04-15.

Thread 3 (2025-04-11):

Missing via stitching near mcu and isolated ground planes

Bedodev, 2025-04-11:
Large parts of the pcb have unfilled, missing or isolated ground planes as there is no via stitching between top and bottom side planes. Ground planes help with thermal relief and signal integrity and it can be fixed by adding vias with such signal between planes.

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

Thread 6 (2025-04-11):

90 degree trace routes

Bedodev, 2025-04-11:
Although functional, right angle traces are not recommended as they can hurt signal integrity.
They are easy to avoid by using a quick succession of 45 degree angles.

Not recommended:
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

Acceptable:
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

Closed 2025-04-15.

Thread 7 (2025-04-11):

Missing model and datasheet link in readme

Bedodev, 2025-04-11:
ESP32 WROVER 0805 Capacitor and ESP32C6 Varistor 1812 components model and datasheet link in readme redirect to github project.

Datasheet and model links for the Varsistor can be found [ComponentSearchEngine](https://componentsearchengine.com/part-view/CT1812K50G/TDK)

Datasheet and model links for the Capacitor can be found on [ComponentSearchEngine](https://componentsearchengine.com/part-view/CPH3225A-2K/Seiko%20Epson%20Corporation)

Closed 2025-04-15.

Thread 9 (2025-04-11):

Missing 3D models

Bedodev, 2025-04-11:
No component package 3D models not present on pcb. Pcb, battery or screen step files not available either. As such, assembly or fitment of existing cases and accessories or future development may be hindered.

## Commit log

2025-04-09 new file: Hardware/OpenBook.sch new file: Hardware/PCB.brd new file: Hardware/board.png new file: Hardware/gerber.zip new file: Images/bord.png new file: Manufacturing/BOM.csv new file: README.md com
    [BOM.csv, OpenBook.sch, PCB.brd]
2025-04-15 Fixed shorted GND on PIN21
    [OpenBook.sch]
2025-04-15 Fixed TX pin disconnection
    [OpenBook.sch]
2025-04-15 Fixed 90 degree routes
    [PCB.brd]
2025-04-15 Silkscreen Text overlapping
    [PCB.brd]

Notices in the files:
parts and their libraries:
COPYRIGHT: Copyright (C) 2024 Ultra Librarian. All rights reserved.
